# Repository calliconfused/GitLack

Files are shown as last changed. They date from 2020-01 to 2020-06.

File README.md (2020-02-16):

# GitLack renamed from FanController
This is a simple project of an enclosure for a 3D printer which controls the fan speed and some lights. But why the name GitLack? It's a German acronym and it means "Gehäuse Innen Temperatur & LED An/Aus Controller Krempel". Word by word translated in English it mean "Enclosure Inside Temperature & LED On/Off Controller Junk". On the other hand, the first syllable Git I want to share my project with you and I was stupid to built direct the right cabinet for my 3D printer. The last syllable for the name which I made the enclosure.

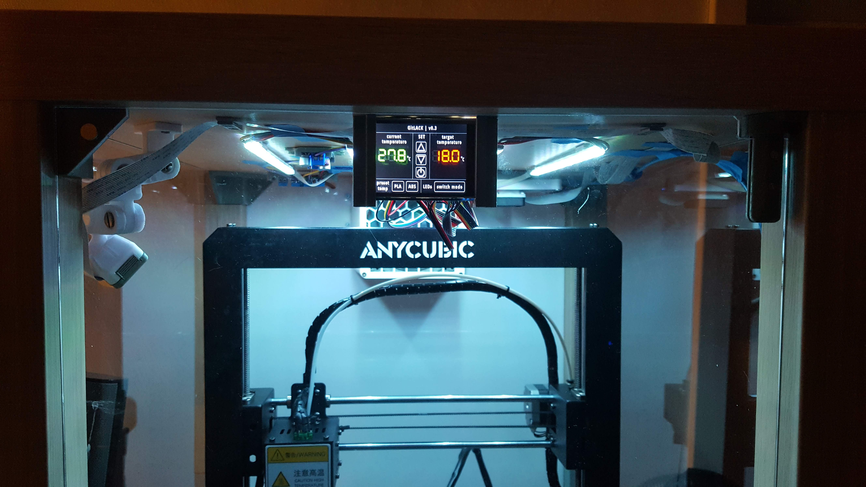
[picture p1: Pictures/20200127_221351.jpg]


Why this project?

So, during my experience with 3D printers I got on Xmas 2019 my new Anycubic 3D Mega. My old CTC printer got some issues during the time but more about this on a later stage. For the old printer I built a mixture of some cabinets out from the bargain basement of the well known Swedish furniture manufacturer. Cheap and already mounted, price was round about of 30 Euro with doors plus 4 LED strips (SMD 5050 with a very easy controller). The problem was that the alignment of the angle wasn't 90 degrees and if you put some weights on top of the cabinet and ... okay, the door was not really parallel opened.

So for the new printer I checked the internet for some collections of the IKEA Lack table. It will look very good in my new office room at home. BUT I want to have a very smart enclosure with a controller of the temperature inside.

My target

For the controller I wanted to use some of the parts what I already had at home and bought just new parts which I really need. So I found in some boxes 1 Arduino Uno R3 clone with some additional pins and SMD, 1 Arduino Nano close, IKEA DIODER LED strips, 12 Volt transformer, PCB plates, resistors, MOSFETs IRLZ34N, screw terminals and kilometer of wires. The parts which I just ordered during the planning phase are 2.8" TFT touchscreen display, temperature sensor GY-BME280, fan 120 mm with 4 pins, XL4015 DC to DC converter (12V to 9V for power supply of the Arduinos).

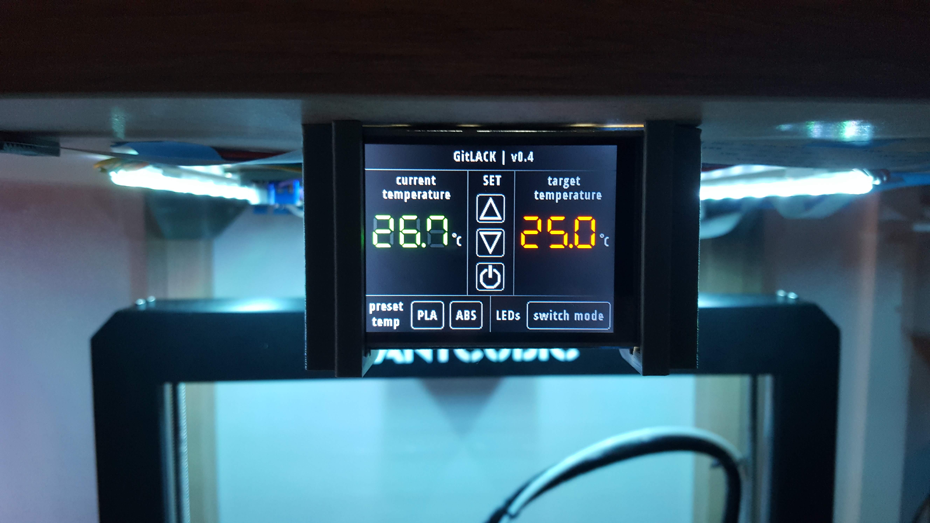
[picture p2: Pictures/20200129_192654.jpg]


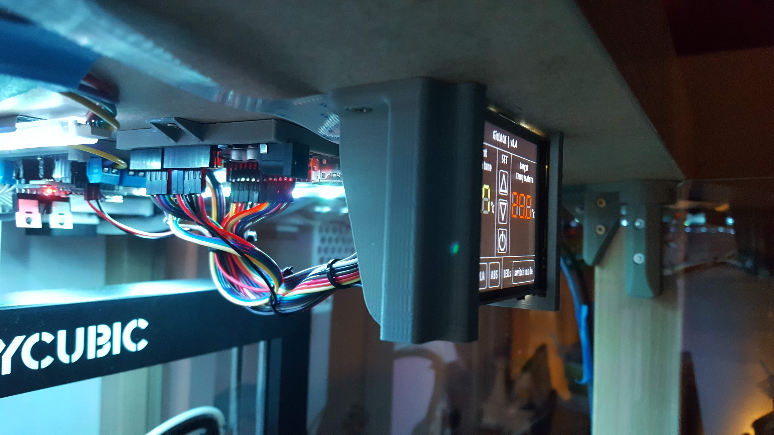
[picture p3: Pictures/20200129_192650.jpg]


The MAIN problem of material

During my research how to handle an automatically temperature inside I found a big issue about the material handle. So it's really an advantage if you cool the inside if you print with PLA and if you work with ABS then you will promote warping. This is still in development to add in the program an adjustment for each material and it's own temperature range. The other problem what I have is I put all Arduinos, the Raspberry PI in the closed cabinet not to waste area outside of the enclosure. Just the 12V transformer is under the base plate. The planning is still in progress.

The other MAIN problem of the Arduino UNO

You see: 2.8" TFT touchscreen display and an Arduino Uno is a nightmare of save memory. As I started with the programming and put the my first sketch to build up the "boot" screen I reached the used memory of 60% ...........
Next problem: the touchscreen will took a lot of pins and all PWM pins are blocked for that. Okay, the card reader is not really necessary for my project but maybe for further updates. We will see.
Someone will say now: hey, why do you don't order a MEGA 2560 clone or similar with more space, speed and pin?
Yeah, you're correct! That's an easier way but my spirit is to use that parts which I already have at home. That's my personal milestone to start with I2C and put the second Arduino in the circuit (in my case the Nano). The master will collect all values from the user, pardon, from the pressed touchscreen and from the temperature sensor and give the values to the slave which will handle the logic of the fan speed and control the LEDs.

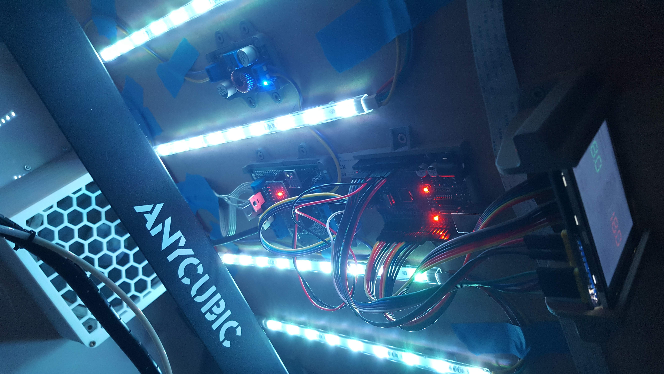
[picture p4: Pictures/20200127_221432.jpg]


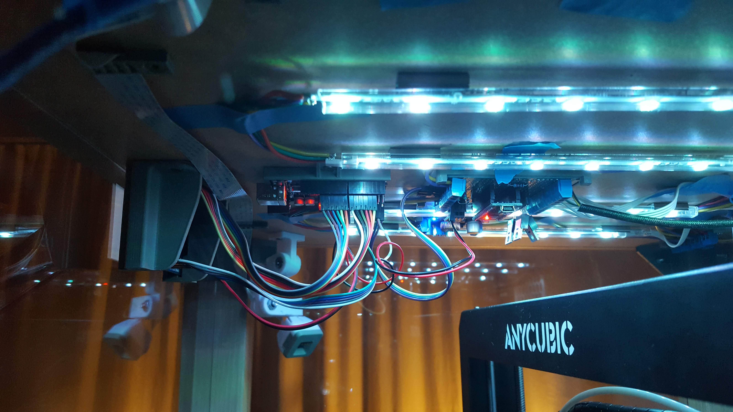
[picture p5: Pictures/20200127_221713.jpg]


Okay ... currently from my side and I will give you in the next days/weeks some updates! Cheers!

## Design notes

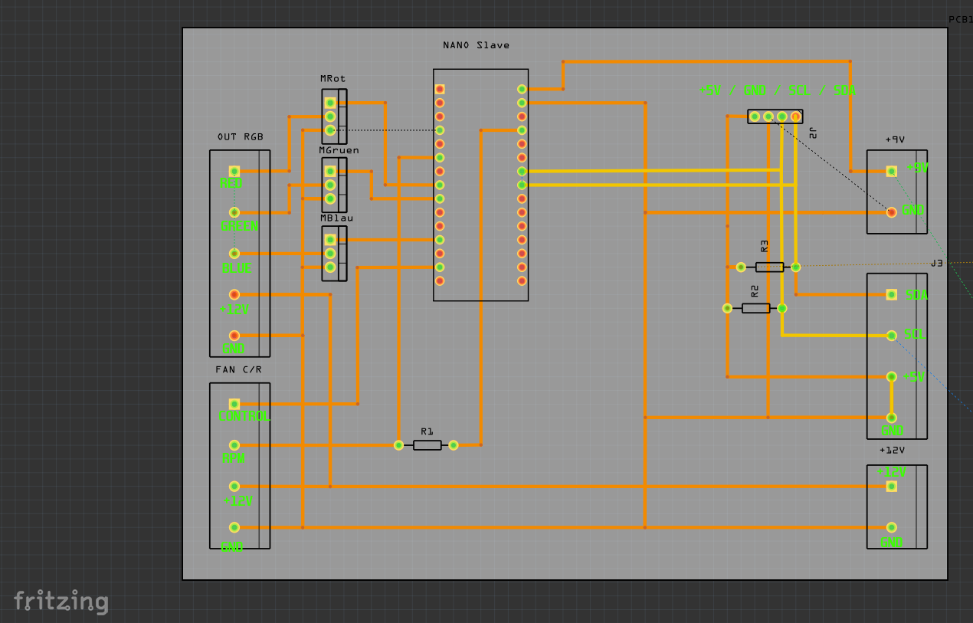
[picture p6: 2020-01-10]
Fritzing/PIN OUT.png

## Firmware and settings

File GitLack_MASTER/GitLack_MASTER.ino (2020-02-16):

#include        <SPI.h>
#include        <Wire.h>
#include        <TouchScreen.h>

#include        <Adafruit_GFX.h>                // Core graphics library
#include        <Adafruit_TFTLCD.h>             // Hardware-specific library
#include        "OpenSansCondensed16pt.h"
#include        "DSEG7REGULAR40.h"
#include        "bitmaps.h"

#include        <Adafruit_BME280.h>

// now a long statement with some fixed values
// here the display and touchscreen values

#define         YP                A3            // must be an analog pin, use "An" notation!
#define         XM                A2            // must be an analog pin, use "An" notation!
#define         YM                9             // can be a digital pin
#define         XP                8             // can be a digital pin

#define         LCD_CS            A3            // Chip Select goes to Analog 3
#define         LCD_CD            A2            // Command/Data goes to Analog 2
#define         LCD_WR            A1            // LCD Write goes to Analog 1
#define         LCD_RD            A0            // LCD Read goes to Analog 0
#define         LCD_RESET         1             // Can alternately just connect to Arduino's reset pin -> it's neccessary if you need the SDA and SCL pins

#define         TS_MINX           120           // touchscreen alternative minimum value in X direction
#define         TS_MAXX           900           // touchscreen alternative minimum value in X direction
#define         TS_MINY           70            // touchscreen alternative minimum value in X direction
#define         TS_MAXY           920           // touchscreen alternative minimum value in X direction

#define         MINPRESSURE       10
#define         MAXPRESSURE       1000

uint16_t        LCD_ID =          0x9341;       // ILI9341 LCD driver, please read your documentation! I don't use all other drivers otherwise the space on the Uno will overrun

float           TEMP_TARGET_MIN = 18.0;         // lowerst adjustable temperature
float           TEMP_TARGET_MAX = 40.0;         // highest adjustable temperature

float           TEMP_PRESET_PLA = 25.0;         // preset for PLA filament
float           TEMP_PRESET_ABS = 35.0;         // preset for ABS filament

int             TFT_ROTATION  =   3;            // orientation of display

int             TS_POSX;
int             TS_POSY;

// some color definition

#define         COLOR_BLACK       0x0000    
#define         COLOR_LIGHTGREY   0xC618
#define         COLOR_DARKGREY    0x7BEF
#define         COLOR_RED         0xF800
#define         COLOR_YELLOW      0xFFE0
#define         COLOR_ORANGE      0xFD20
#define         COLOR_GREENYELLOW 0xAFE5
#define         COLOR_ARSENIC     0x2965

// now the GY-BME280 values

uint16_t        BME_ID =          0x76;         // BME ID

// and some fixed values as general setup

int             SELECTED_FAN;                     // 0 = OFF, 1 = automatic
int             SELECTED_LED;                     // 0 = OFF, 1 = 50%, 2 = 100%
int             SELECTED_FAN_LAST;                // save the last selected value for the fan

float           TEMPERATURE_CURRENT;              // save the current temperature
float           TEMPERATURE_LAST;                 // save the last temperature

float           TEMPERATURE_TARGET;               // save the target temperature
float           TEMPERATURE_TARGET_LAST;          // save the last target ... ? ... temperature

// instead of the delay command which won't work in this sketch I prefer to use the millis command together with an if statement

unsigned long   TIMER_TS_DELAY;                   
long            TIMER_TS_REST =   1000;           // count in milli seconds
unsigned long   TIMER_TE_DELAY;
long            TIMER_TE_REST =   1500;           // count in milli seconds
unsigned long   TIMER_GL_DELAY;
long            TIMER_GL_REST =   5000;           // count in milli seconds

unsigned long   TIMER_MENU_DELAY;
long            TIMER_MENU_REST = 3600000;        // count in milli seconds - a general refresh of the screen


TouchScreen ts = TouchScreen(XP, YP, XM, YM, 300); // mesaure the resistance between XP and XM and change the value
TSPoint p;

Adafruit_TFTLCD tft(LCD_CS, LCD_CD, LCD_WR, LCD_RD, LCD_RESET);
Adafruit_BME280 bme;

void setup(void) {
  
  Serial.begin(9600);

  Serial.println("INITALIZING");
  
  Wire.begin();
  
  TEMPERATURE_CURRENT = 0;
  TEMPERATURE_LAST = 0;  

  SELECTED_FAN = 0;
  SELECTED_FAN_LAST = 0;
  SELECTED_LED = 2;

  TEMPERATURE_TARGET = 20;
  TEMPERATURE_TARGET_LAST = TEMPERATURE_TARGET;

  TS_POSX = 0;
  TS_POSY = 0;
  
  TIMER_TS_DELAY = millis();
  TIMER_TE_DELAY = millis();
  TIMER_GL_DELAY = millis();
  TIMER_MENU_DELAY = millis() + TIMER_MENU_REST;
  
  bme.begin(BME_ID);
  
  tft.reset();
  tft.begin(LCD_ID);
  
  tft.setRotation(TFT_ROTATION);
  
  pinMode(13, OUTPUT);
  
  vDrawMenu();                // draw grid and all the other nice stuff
  vSendUpdateToSlave();       // send an update to the slave device

}

void loop() {

  digitalWrite(13, HIGH);
  TSPoint p = ts.getPoint();
  digitalWrite(13, LOW); 

  // if sharing pins, you'll need to fix the directions of the touchscreen pins
  // I don't finished this if statement with option 1, 2 and 4, need support!
  
  if ( TFT_ROTATION == 1) {         // needs to be adjust
    //pinMode(XP, OUTPUT);
    pinMode(XM, OUTPUT);
    pinMode(YP, OUTPUT);
    //pinMode(YM, OUTPUT); 
  } else if ( TFT_ROTATION == 2) {  // needs to be adjust
    //pinMode(XP, OUTPUT);
    pinMode(XM, OUTPUT);
    pinMode(YP, OUTPUT);
    //pinMode(YM, OUTPUT); 
  } else if ( TFT_ROTATION == 3) {  // THAT WORKS!
    pinMode(XM, OUTPUT);
    pinMode(YP, OUTPUT);
  } else if ( TFT_ROTATION == 4) {  // needs to be adjust
    //pinMode(XP, OUTPUT);
    pinMode(XM, OUTPUT);
    pinMode(YP, OUTPUT);
    //pinMode(YM, OUTPUT); 
  }


  if ( p.z > MINPRESSURE && p.z < MAXPRESSURE && TIMER_TS_DELAY <= millis() ) {

    // orienation ... need if statement in combination with TFT_ROTATION
    if ( TFT_ROTATION == 1 ) {          // needs to be adjust
      TS_POSX = map(p.x, TS_MINX, TS_MAXX, tft.width(), 0);
      TS_POSY = map(p.y, TS_MINY, TS_MAXY, 0, tft.height());
    } else if ( TFT_ROTATION == 2 ) {   // THAT WORKS!
      TS_POSX = map(p.x, TS_MINX, TS_MAXX, tft.width(), 0);
      TS_POSY = map(p.y, TS_MINY, TS_MAXY, 0, tft.height());
    } else if ( TFT_ROTATION == 3 ) {   // THAT WORKS!
      TS_POSX = map(p.y, TS_MINX, TS_MAXX, 0, tft.width());
      TS_POSY = map(p.x, TS_MINY, TS_MAXY, 0, tft.height());
    } else if ( TFT_ROTATION == 4 ) {   // needs to be adjust
      TS_POSX = map(p.x, TS_MINX, TS_MAXX, tft.width(), 0);
      TS_POSY = map(p.y, TS_MINY, TS_MAXY, 0, tft.height());
    }

    TIMER_TS_DELAY = millis() + TIMER_TS_REST;

    // now the long if statement of the pressed position
    // target temperature up
    if  (( TS_POSX >= 142 ) && ( TS_POSY >=  62 ) && ( TS_POSX <= 178 ) && ( TS_POSY <=  98 )) {

      if ( SELECTED_FAN == 0 ) {
        TEMPERATURE_TARGET = TEMPERATURE_TARGET_LAST;
        SELECTED_FAN = 1;
      } else 
      if ( SELECTED_FAN == 1 ) { 
        TEMPERATURE_TARGET ++;
        if ( TEMPERATURE_TARGET > TEMP_TARGET_MAX ) {
          TEMPERATURE_TARGET = TEMP_TARGET_MAX;
          TEMPERATURE_TARGET_LAST = TEMPERATURE_TARGET;
        }
        SELECTED_FAN = 1;
      }
      
      vShowTemperatureTarget();
      vSendUpdateToSlave();
      
    } else
  
    // target temperature down
    if  (( TS_POSX >= 142 ) && ( TS_POSY >= 106 ) && ( TS_POSX <= 178 ) && ( TS_POSY <= 142 )) {
      
      if ( SELECTED_FAN == 0 ) {
        TEMPERATURE_TARGET = TEMPERATURE_TARGET_LAST;
        SELECTED_FAN = 1;
      } else 
      if ( SELECTED_FAN == 1 ) { 
        TEMPERATURE_TARGET --;
        if ( TEMPERATURE_TARGET < TEMP_TARGET_MIN ) {
          TEMPERATURE_TARGET = TEMP_TARGET_MIN;
          TEMPERATURE_TARGET_LAST = TEMPERATURE_TARGET;
        }
        SELECTED_FAN = 1;
      }      
      vShowTemperatureTarget();
      vSendUpdateToSlave();
      
    } else
  
    // fan off
    if  (( TS_POSX >= 142 ) && ( TS_POSY >= 150 ) && ( TS_POSX <= 178 ) && ( TS_POSY <= 186 )) {

      SELECTED_FAN = 0;
      
      vShowTemperatureTarget();
      vSendUpdateToSlave();
      
    } else
  
    // preset PLA
    if  (( TS_POSX >=  58 ) && ( TS_POSY >= 200 ) && ( TS_POSX <= 100 ) && ( TS_POSY <= 236 )) {

      SELECTED_FAN = 1;
      TEMPERATURE_TARGET = TEMP_PRESET_PLA;
      TEMPERATURE_TARGET_LAST = TEMPERATURE_TARGET;
      
      vShowTemperatureTarget();
      vSendUpdateToSlave();
      
    } else 
  
    // preset ABS
    if  (( TS_POSX >= 108 ) && ( TS_POSY >= 200 ) && ( TS_POSX <= 150 ) && ( TS_POSY <= 236 )) {

      SELECTED_FAN = 1;
      TEMPERATURE_TARGET = TEMP_PRESET_ABS;
      TEMPERATURE_TARGET_LAST = TEMPERATURE_TARGET;
      
      vShowTemperatureTarget();
      vSendUpdateToSlave();
      
    } else
  
    // switch LED
    if  (( TS_POSX >= 208 ) && ( TS_POSY >= 200 ) && ( TS_POSX <= 316 ) && ( TS_POSY <= 236 )) {
      
      SELECTED_LED ++;
  
      if ( SELECTED_LED >= 3 ) {
        SELECTED_LED = 0;
      }

      vSendUpdateToSlave();
      
    }

    // reset touchscreen positions
    TS_POSX = 0;  TS_POSY = 0;

  }

  if ( TIMER_TE_DELAY <= millis() ) {
    vShowTemperatureCurrent();

    if ( SELECTED_FAN == 1 ) {
      vSendUpdateToSlave();
    }
    
    TIMER_TE_DELAY = millis() + TIMER_TE_REST;
  }

  if ( TIMER_GL_DELAY <= millis() ) {
    vSendUpdateToSlave;
    TIMER_GL_DELAY = millis() + TIMER_GL_REST;
  }

  if ( TIMER_MENU_DELAY <= millis() ) {
    vDrawMenu();
    TIMER_MENU_DELAY = millis() + TIMER_MENU_REST;
  }

}

void vShowTemperatureCurrent() {
    
  TEMPERATURE_CURRENT = bme.readTemperature();
  TEMPERATURE_CURRENT = TEMPERATURE_CURRENT * 10;
  TEMPERATURE_CURRENT = (int) TEMPERATURE_CURRENT;
  TEMPERATURE_CURRENT = TEMPERATURE_CURRENT / 10;

  if ( TEMPERATURE_CURRENT != TEMPERATURE_LAST ) {

    tft.setFont(&DSEG7REGULAR40);
    tft.setTextColor(COLOR_ARSENIC);
    tft.setCursor(6, 130);  tft.print("88.8");
    
    tft.setCursor(6, 130);

    if ( TEMPERATURE_CURRENT <= 30 ) {
      tft.setTextColor(COLOR_GREENYELLOW);  
    } else
    if ( TEMPERATURE_CURRENT > 30 && TEMPERATURE_CURRENT <= 45 ) {
      tft.setTextColor(COLOR_YELLOW);  
    } else    
    if ( TEMPERATURE_CURRENT > 45 ) {
      tft.setTextColor(COLOR_ORANGE);  
    }     
    tft.setFont(&DSEG7REGULAR40);
    tft.print(TEMPERATURE_CURRENT, 1);
 
  }

  TEMPERATURE_LAST = TEMPERATURE_CURRENT;
    
}

void vShowTemperatureTarget() {

  if ( SELECTED_FAN == 0 ) {
    
    tft.setFont(&DSEG7REGULAR40);
    tft.setTextColor(COLOR_ARSENIC);
    tft.setCursor(196, 130);            tft.print("88.8");    
  
    tft.setTextColor(COLOR_RED);
    tft.setCursor(196, 130);          tft.print(";:");
    tft.setTextColor(COLOR_ARSENIC);  tft.print(".");
    tft.setTextColor(COLOR_RED);      tft.print(":");
    
  } else
  if ( SELECTED_FAN == 1 ) {
    
    tft.setFont(&DSEG7REGULAR40);
    tft.setTextColor(COLOR_ARSENIC);
    tft.setCursor(196, 130);            tft.print("88.8");    
    
    tft.setTextColor(COLOR_RED);
    tft.setCursor(196, 130);          tft.print(TEMPERATURE_TARGET, 1);
  } 
  
  TEMPERATURE_TARGET_LAST = TEMPERATURE_TARGET;
  
}

void vSendUpdateToSlave() {

  // send to slave
  Wire.beginTransmission(2);
  // send LED value
  Wire.write((byte) SELECTED_LED);
  // send fan option
  Wire.write((byte) SELECTED_FAN);
  // send current temperature
  Wire.write((byte) TEMPERATURE_CURRENT);
  // send target temperature
  Wire.write((byte) TEMPERATURE_TARGET);
  Wire.endTransmission();
  
}

void vDrawMenu() {

  tft.fillScreen(COLOR_BLACK);
  
  tft.setTextColor(COLOR_LIGHTGREY);
  tft.setFont(&Open_Sans_Condensed_Bold_16);

  // head
  tft.setCursor(112, 20);   tft.print("GitLACK | v0.4");

  // grid
  tft.drawFastHLine(0, 31, 320, COLOR_DARKGREY);
  tft.drawFastHLine(0, 192, 320, COLOR_DARKGREY);
  
  tft.drawFastVLine(130, 31, 161, COLOR_DARKGREY);
  tft.drawFastVLine(190, 31, 161, COLOR_DARKGREY);
  tft.drawFastVLine(160, 192, 48, COLOR_DARKGREY);

  // left area of current temperature
  tft.drawCircle(113, 114, 1, COLOR_LIGHTGREY);
  tft.drawCircle(113, 114, 2, COLOR_LIGHTGREY);

  tft.setCursor(116, 128);  tft.print("C");  
  tft.setCursor(39, 50);    tft.print("current");
  tft.setCursor(22, 68);    tft.print("temperature");

  // right area of target temperature
  tft.drawCircle(303, 114, 1, COLOR_LIGHTGREY);
  tft.drawCircle(303, 114, 2, COLOR_LIGHTGREY);

  tft.setCursor(306, 128);  tft.print("C");  
  tft.setCursor(233, 50);   tft.print("target");
  tft.setCursor(216, 68);   tft.print("temperature");

  // middle area to set temperature
  tft.setCursor(150, 50);  tft.print("SET"); 
  
  tft.drawBitmap(144, 64, SYMBOL_arrowup, 32, 32, COLOR_LIGHTGREY);
  tft.drawRoundRect(142, 62, 36, 36, 4, COLOR_LIGHTGREY);
  
  tft.drawBitmap(144, 108, SYMBOL_arrowdown, 32, 32, COLOR_LIGHTGREY);
  tft.drawRoundRect(142, 106, 36, 36, 4, COLOR_LIGHTGREY);
  
  tft.drawBitmap(144, 152, SYMBOL_switchoff, 32, 32, COLOR_LIGHTGREY);
  tft.drawRoundRect(142, 150, 36, 36, 4, COLOR_LIGHTGREY);

  // lower left area to set the preset
  tft.setCursor(4, 212);  tft.print("preset"); 
  tft.setCursor(8, 232);  tft.print("temp");

  tft.setCursor(66, 224);  tft.print("PLA"); 
  tft.drawRoundRect(58, 200, 42, 36, 4, COLOR_LIGHTGREY);
  tft.setCursor(116, 224);  tft.print("ABS"); 
  tft.drawRoundRect(108, 200, 42, 36, 4, COLOR_LIGHTGREY);

  // lower right area to set the LEDs
  tft.setCursor(168, 224);  tft.print("LEDs"); 

  tft.setCursor(217, 224);  tft.print("switch mode"); 
  tft.drawRoundRect(208, 200, 108, 36, 4, COLOR_LIGHTGREY);
  
  Serial.println("OK - PASSED!");
  Serial.println("WELCOME to GitLACK | v0.4");

  TEMPERATURE_LAST = 0;
  vShowTemperatureCurrent();
  vShowTemperatureTarget();
    
}

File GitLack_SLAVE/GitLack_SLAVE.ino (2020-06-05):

#include  <Wire.h>

#define   LED_PIN_R               5
#define   LED_PIN_G               6
#define   LED_PIN_B               9

#define   FAN_CONTROL             11
#define   FAN_RPM                 3
#define   INTERRUPT_RPM           0
#define   UPDATE_TIMER            500

byte      TEMP_DIFF_LOW           = 5;
byte      TEMP_DIFF_HIGH          = 10;
byte      LOWEST_FAN_SPEED        = 63;
byte      HIGHEST_FAN_SPEED       = 255;

byte      SELECTED_LED;
byte      SELECTED_LED_LAST;
byte      SELECTED_FAN;
byte      SELECTED_FAN_LAST;
byte      TEMPERATURE_CURRENT;
byte      TEMPERATURE_TARGET;
byte      FADE;
byte      TEMPERATURE_AUTO_MIN;
byte      TEMPERATURE_AUTO_MAX;
byte      TEMPERATURE_MAX         = 45;

byte      COUNTER_RPM             = 0;

unsigned long LAST_TIMER          = 0;

void setup() {

  SELECTED_LED = 0;
  SELECTED_FAN = 0;
  TEMPERATURE_CURRENT = 0;
  TEMPERATURE_TARGET = 0;
  
  Serial.begin(9600);
  Wire.begin(2);
  Wire.onReceive(receiveEvent);
  Serial.println("OK!");

  analogWrite(FAN_CONTROL, 0);
  
  /*
  pinMode(FAN_CONTROL, OUTPUT);
  pinMode(FAN_RPM, INPUT);
  digitalWrite(FAN_RPM, HIGH);
  attachInterrupt(INTERRUPT_RPM, vRPM_FAN, FALLING);
  */
  
}

void receiveEvent(int bytes) {

  if (bytes != 4) {
    while ( Wire.available() ) {
      Wire.read();
    }
    return;
  }

  if ( Wire.available() ) {
    SELECTED_LED = Wire.read();

    if ( Wire.available() ) {
      SELECTED_FAN = Wire.read();  

      if ( Wire.available() ) {
        TEMPERATURE_CURRENT = Wire.read();
        
        if ( Wire.available() ) {
          TEMPERATURE_TARGET = Wire.read();
        }
      }
    }
  }

}

void loop() {

  if ( SELECTED_FAN == 0 ) {
    analogWrite(FAN_CONTROL, 0);
  }

  if ( SELECTED_FAN == 1 ) {

    TEMPERATURE_AUTO_MIN = TEMPERATURE_TARGET;
    TEMPERATURE_AUTO_MAX = TEMPERATURE_TARGET + TEMP_DIFF_HIGH;
    
    if ( TEMPERATURE_CURRENT < TEMPERATURE_TARGET ) {
      analogWrite(FAN_CONTROL, 0);
    } else
    if ( TEMPERATURE_CURRENT >= TEMPERATURE_TARGET && TEMPERATURE_CURRENT <= TEMPERATURE_AUTO_MAX ) {
      FADE = map(TEMPERATURE_CURRENT, TEMPERATURE_AUTO_MIN, TEMPERATURE_AUTO_MAX, LOWEST_FAN_SPEED, HIGHEST_FAN_SPEED);
      analogWrite(FAN_CONTROL, FADE);
    } else
    if ( TEMPERATURE_CURRENT > TEMPERATURE_AUTO_MAX ) {
      analogWrite(FAN_CONTROL, HIGHEST_FAN_SPEED);
    }

  } 
  
  if ( SELECTED_LED_LAST != SELECTED_LED ) {
    
    if ( SELECTED_LED == 0 ) {
      FADE = 0;
    } else
    if ( SELECTED_LED == 1 ) {
      FADE = 88;
    } else
    if ( SELECTED_LED == 2 ) {
      FADE = 255;
    }     
    analogWrite(LED_PIN_R, FADE);
    analogWrite(LED_PIN_G, FADE);
    analogWrite(LED_PIN_B, FADE);

    SELECTED_LED_LAST = SELECTED_LED;
  }

  if (millis() - LAST_TIMER >= UPDATE_TIMER) {
    //detachInterrupt(0);
    //Serial.println(COUNTER_RPM * (60 / 1));
    //COUNTER_RPM = 0;
    //LAST_TIMER = millis();
    //attachInterrupt(0, vRPM_FAN, FALLING);
  }
  
}

void vRPM_FAN() {
  COUNTER_RPM++;
}

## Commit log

2020-01-04 first sketch with the tft lcd and touch screen
    the ino doesn't contains all comments! be careful with the LCD_RESET! It's now on pin 1 and not on the A4 pin (will be needed for the I2C communication with other arduino nano and the BME280 sensor)
    fonts not longer supports small characters and 7 segment just numbers
2020-01-07 small little changes and one test with customer symboles
    [wiring sketch.fzz]
2020-01-10 Some updates and fixed
    [wiring sketch.fzz]
2020-01-19 Updated slave
    Issue open: automatical speed control of fan
    [GitLack_MASTER.ino, GitLack_SLAVE.ino]
2020-01-23 Auto temperature optimized and screenupdate after one hour
2020-01-29 pictures from enclosure added
